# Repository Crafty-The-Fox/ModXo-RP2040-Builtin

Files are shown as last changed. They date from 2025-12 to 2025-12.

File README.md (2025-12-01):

# ModXo-RP2040-Included-Edition

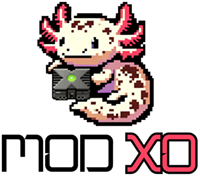
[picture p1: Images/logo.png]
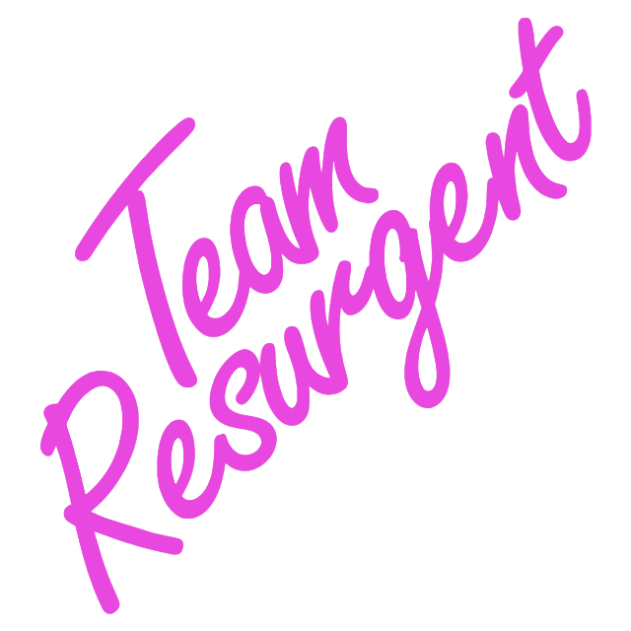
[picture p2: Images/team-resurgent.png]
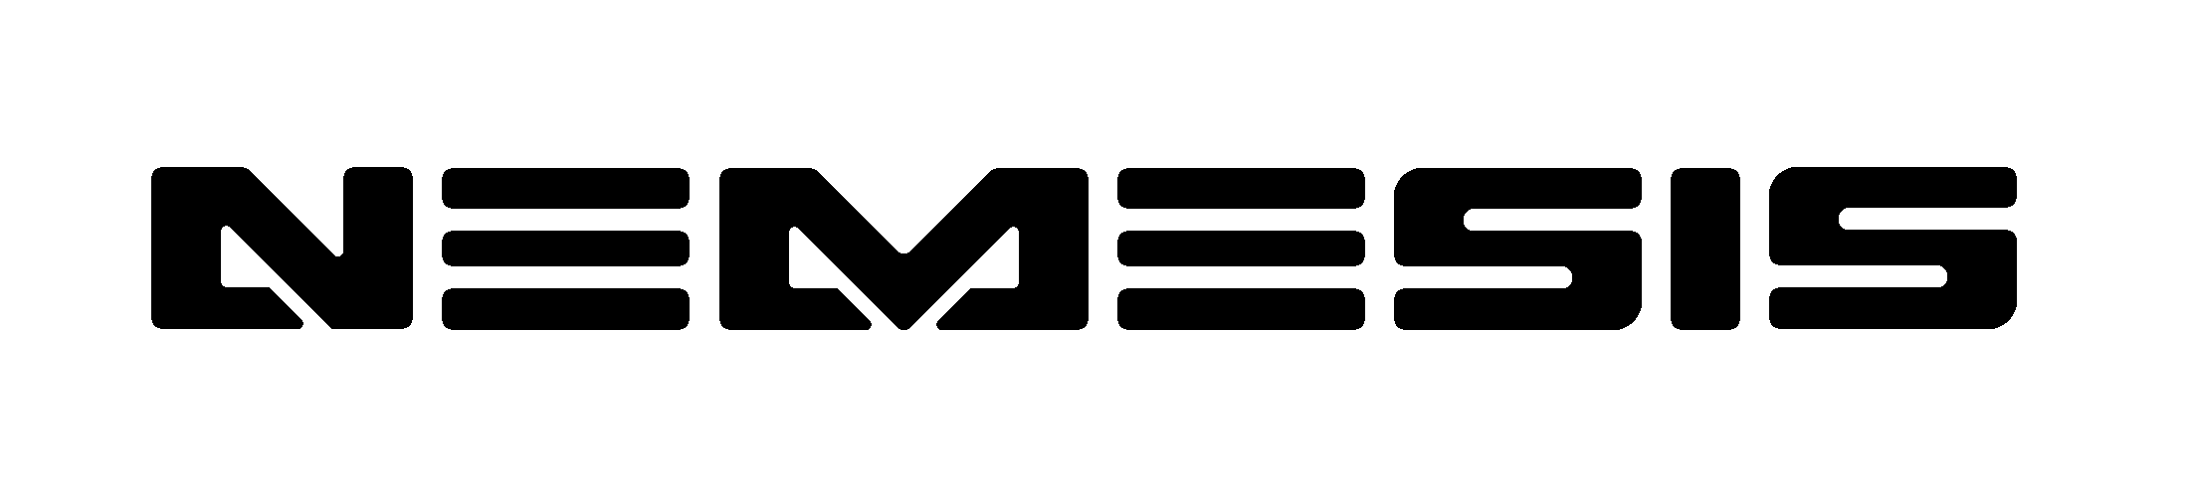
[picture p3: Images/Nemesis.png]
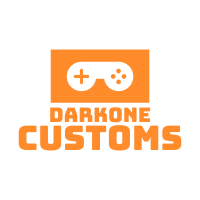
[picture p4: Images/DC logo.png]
   



A carrier board for the ModXo V1.0 with added support for Epimetheus. Based off of Darkone83's work. (reversed from gerbers and provided documents on the github page)

NOTE: anything after this is from the other repo.

This is designed around Team Resutgent's and Shalx's work on ModXo an open-source modchip, with additional support for OfficialTeamUIX's Epimetheus incorporated into the PCB

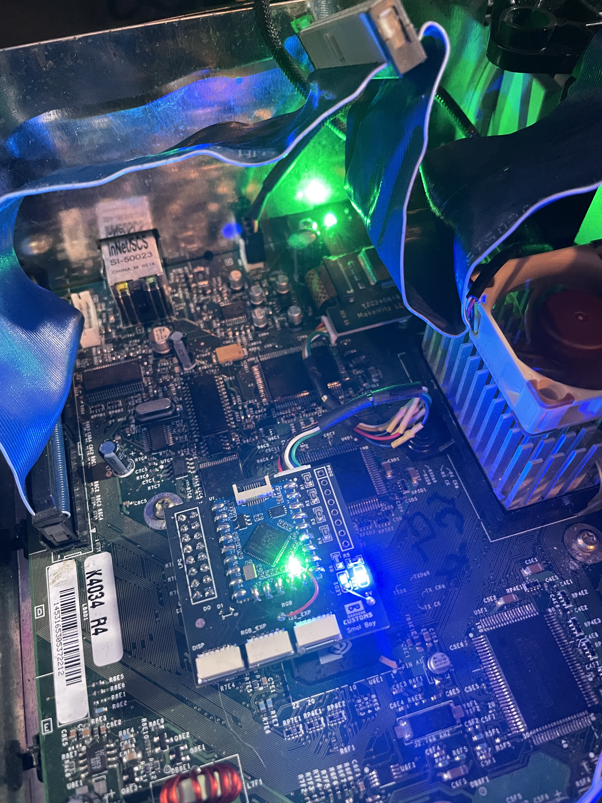
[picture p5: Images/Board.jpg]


Mouser Cart: <a href="https://www.mouser.com/ProjectManager/ProjectDetail.aspx?AccessID=a62729557a">Here</a>

RP2040 Tiny: <a href="https://www.aliexpress.us/item/3256805837992528.html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">AliExpress</a>, <a href="https://www.amazon.com/gp/product/B0CHDW1MY5/ref=ppx_yo_dt_b_asin_title_o02_s00?ie=UTF8&psc=1">Amazon</a>

JST SH 6 Pin Cables: 

<a href="https://www.aliexpress.us/item/3256804332710255.html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,scm-url:1007.40050.354490.0,pvid:6b58b5af-718a-4929-bfb1-9a0c24fd9d3c,tpp_buckets:668%232846%238112%231997&pdp_npi=4%40dis%21USD%210.46%210.40%21%21%210.46%210.40%21%402103241117302619299196939e5dfc%2112000029449896682%21rec%21US%21196794698%21X&utparam-url=scene%3ApcDetailTopMoreOtherSeller%7Cquery_from%3A">AliExpress</a> Select 100mm length, 6 Pin 10 Pcs, SH 1.0MM Dual for Color, Request same direction!!!

Or if you want to build out your own you can use this listing on <a href="https://www.amazon.com/gp/product/B0BKSNMCV4/ref=ppx_yo_dt_b_asin_title_o03_s00?ie=UTF8&psc=1">Amazon</a>

For more information on the software side of things and the ModXo project please visit: https://github.com/Team-Resurgent/Modxo

For more information on Epimetheus please visit: https://github.com/OfficialTeamUIX/Epimetheus 

### Notice

No firmware is provided for the STM32 you will need to either code your own firmware or legally obtain a firmware image

#### Builder's note

If your XBOX is a revision 1.6 you will need to rebuild the LPC manually or use a LPC rebuild PCB.

# Purchase

Fully assembled boards and PCB's can be purchased via <a href="https://darkonecustoms.com">Darkone Customs</a>

PCB Only: <a href="https://www.darkonecustoms.com/store/p/modxo-epimetheus-pcb">Here</a>

Fully Assembled Board: <a href="https://www.darkonecustoms.com/store/p/modxo-epimetheus-fully-assembled">Here</a> *Fully assembled boards do not contain any firmware for the STM32*

# Navigation

Both the Bom and iBOMS are located in the root folder. iBOMS are included for the full-size board and the new Smol revision, Large board has been moved to archive

Archive: Will contain older functional gerbers and pick and place files as the board revs, along with older board images and older iBOMS.

Images: Contains branding images along with PCB images for the full-size and the Smol board, the schematic is also included here and is the same for both boards along with images of the various header pinouts and soldering locations

Smol: Contains gerbers for the Smol board along with the pick-and-place file

# Assembly

### ModXo

It's recommended to assemble the ModXo potion of the board first and test it. These parts include U1, D1, LED2, R1-4, R6, and the LPC headder. After functionality has been confirmed move on to the VCC circuit assembly

### VCC circuit

The VCC Circuit pulls 5V and GND from the LPC 5V on the 5V pad and GND can be found on PINs 2,12. The VCC circuit consists of the following parts U5, L1, C1-C2. After assembly, you can test PIN 5 of U5 to ensure a stable 3.3V output. Once you have confirmed you have 3.3V continue to assemble the STM32 circuit

### STM32

The STM32F030C8C6 is the core of the Epimetheus functionality portion of the board these components include U2. R7-10, C3-C6. Do not install R9 until you have programmed your STM32. Once assembly is complete you can proceed to program your STM32 Review the NRST Harness diagram and temporarily install it for programming. The NRST wire will connect to the top pad of R9 (the one closest to the MCU) and the GND side to any viable GND source. Remove the NRST harness once you have verified and tested your firmware. Install R9 to complete the STM32 circuit. SDA is pulled directly from PIN 13 of the LPC header and SCL is pulled directly from PIN 14. Pinouts will be listed below. Proceed to Port assembly

#### STM32 PWR and Enable
Attach a +5V source to the 5V pad on the topside of the board. On the back of the board jumper, both boxes are labeled enable with a solder blob. This was designed this way to assist in isolating the STM32 and the ModXo. As a quick tap, you can pull +5V from the bottom of LED2. 

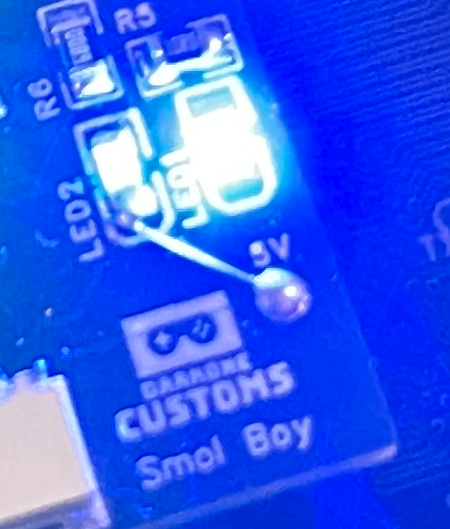
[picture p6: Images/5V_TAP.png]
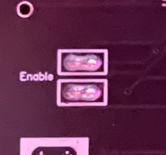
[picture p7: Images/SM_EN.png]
 

### Port Assembly

Install U3, DISP, i2c_EXP, RGB_EXP, if using the RGB_EXP port install the jumper wire from the tiny to the RGB TP to enable the functionality.

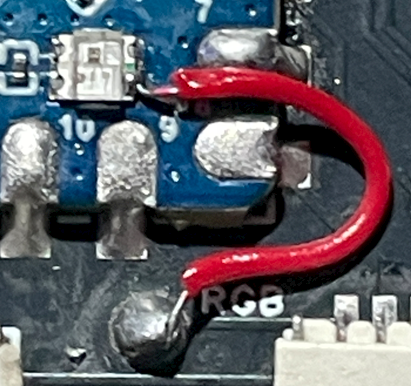
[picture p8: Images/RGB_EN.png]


### Notice

Soldering in the header for PROG is optional as you can insert pins and lightly wedge them in place to program the chip, R5, R6, LED1, and LED2 are optional. LED2 needs to be installed reverse of what the silk screen has labeled

# Installation

## 1.0 - 1.4

Install your pin header, Run a short wire from any suitable D0 point to either ground or the D0 point on the ModXo-Basic. Plug-in your ModXo-Basic to the XBOX LPC port (after you have flashed your favorite firmware) and enjoy.

#### D0 Point options

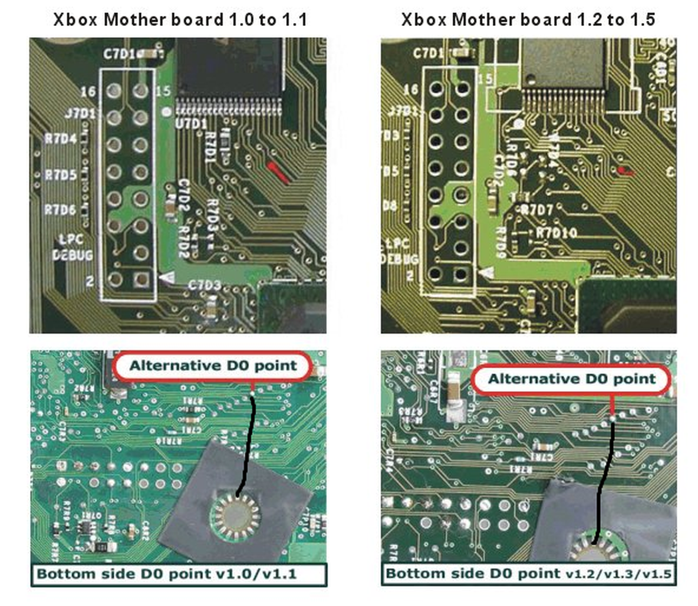
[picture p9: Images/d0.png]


## 1.6

Either install a LPC rebuild QSB or rebuild your LPC per the rebuild diagram below. Plug-in your ModXo-Basic to the XBOX LPC port (after you have flashed your favorite firmware) and enjoy.

#### 1.6 LPC rebuild

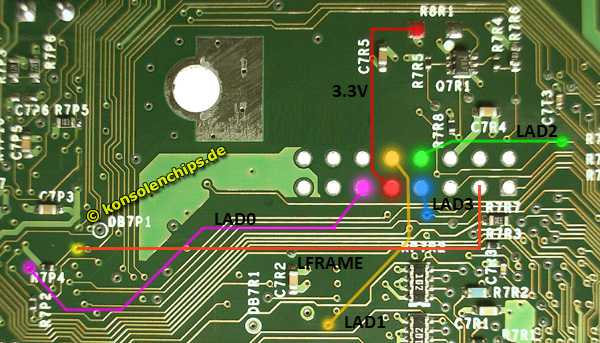
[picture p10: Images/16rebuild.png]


# Pinouts 

Xbox LPC

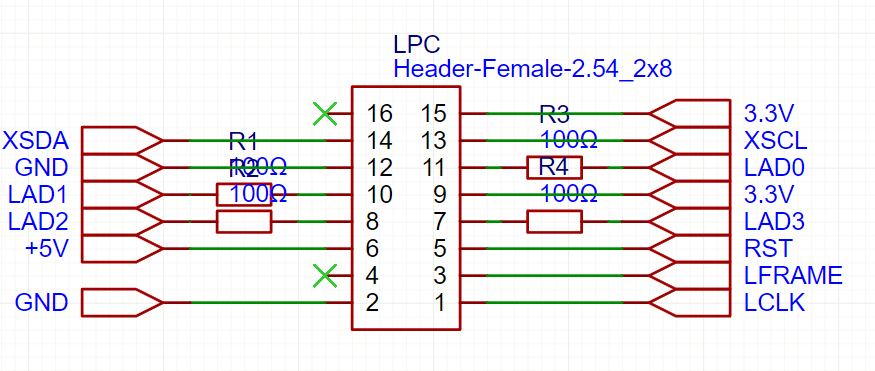
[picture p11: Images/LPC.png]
atl_text


Prog: 

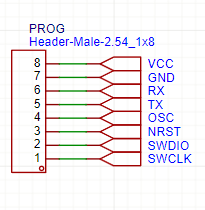
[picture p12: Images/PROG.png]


U3: 

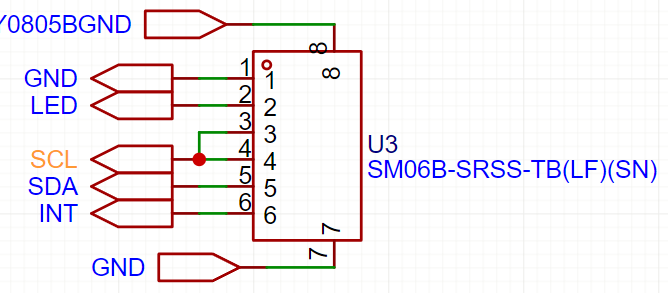
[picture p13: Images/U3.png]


RGB_EXP: 

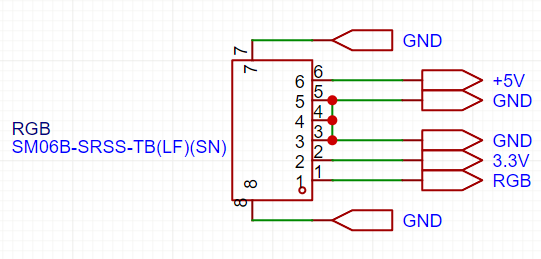
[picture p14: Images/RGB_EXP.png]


i2c_EXP: 

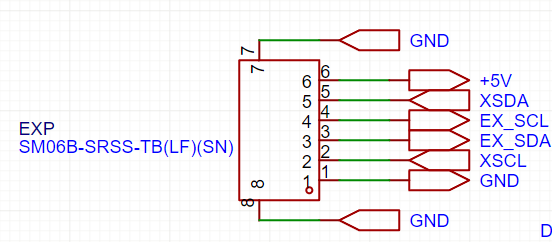
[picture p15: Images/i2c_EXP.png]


DISP: 

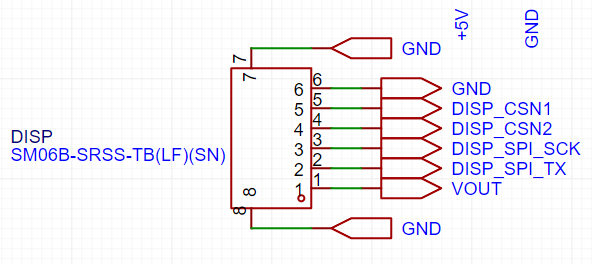
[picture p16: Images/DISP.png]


NRST Harnes:

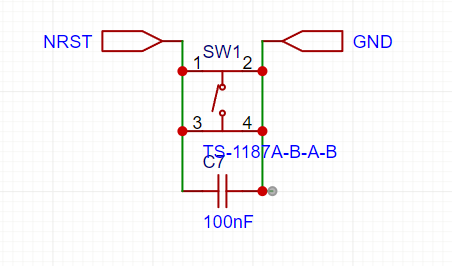
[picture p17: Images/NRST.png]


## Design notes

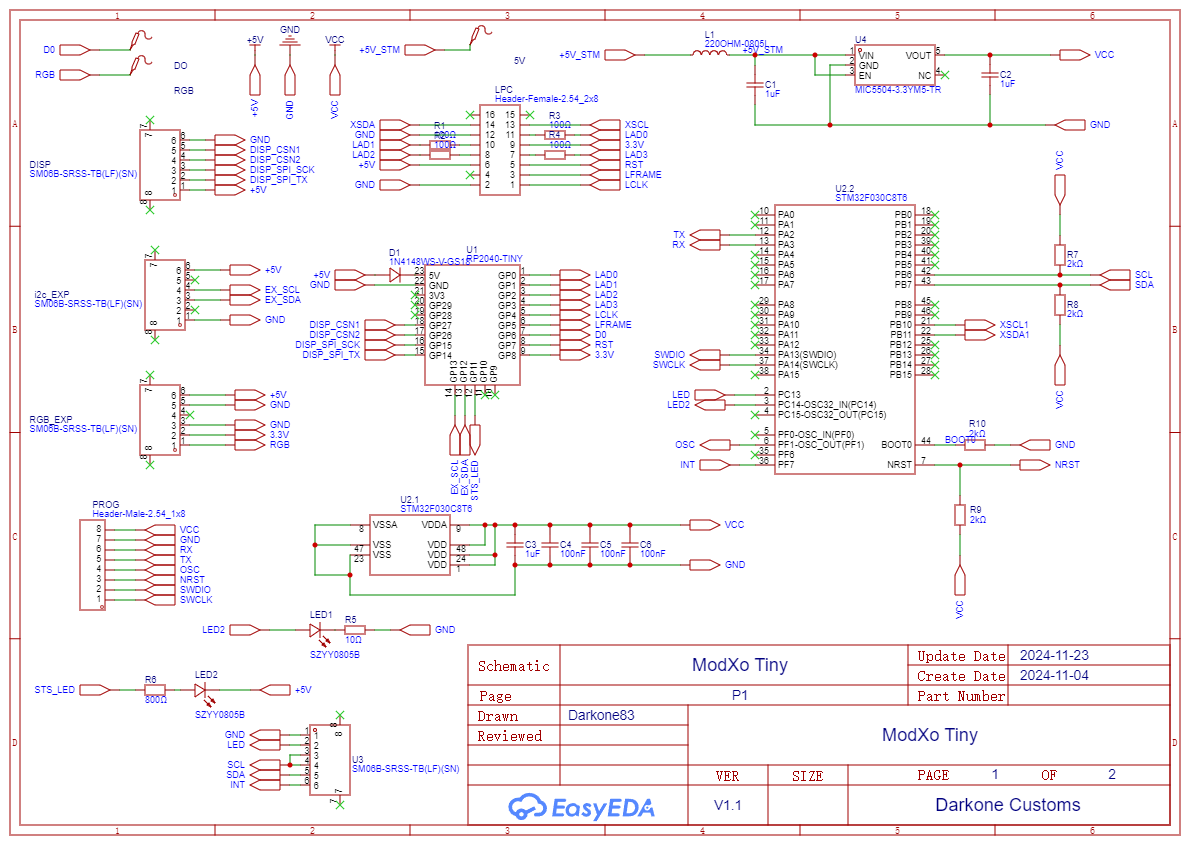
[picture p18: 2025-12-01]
Images/Schematic_ModXo+Epimetheus.png

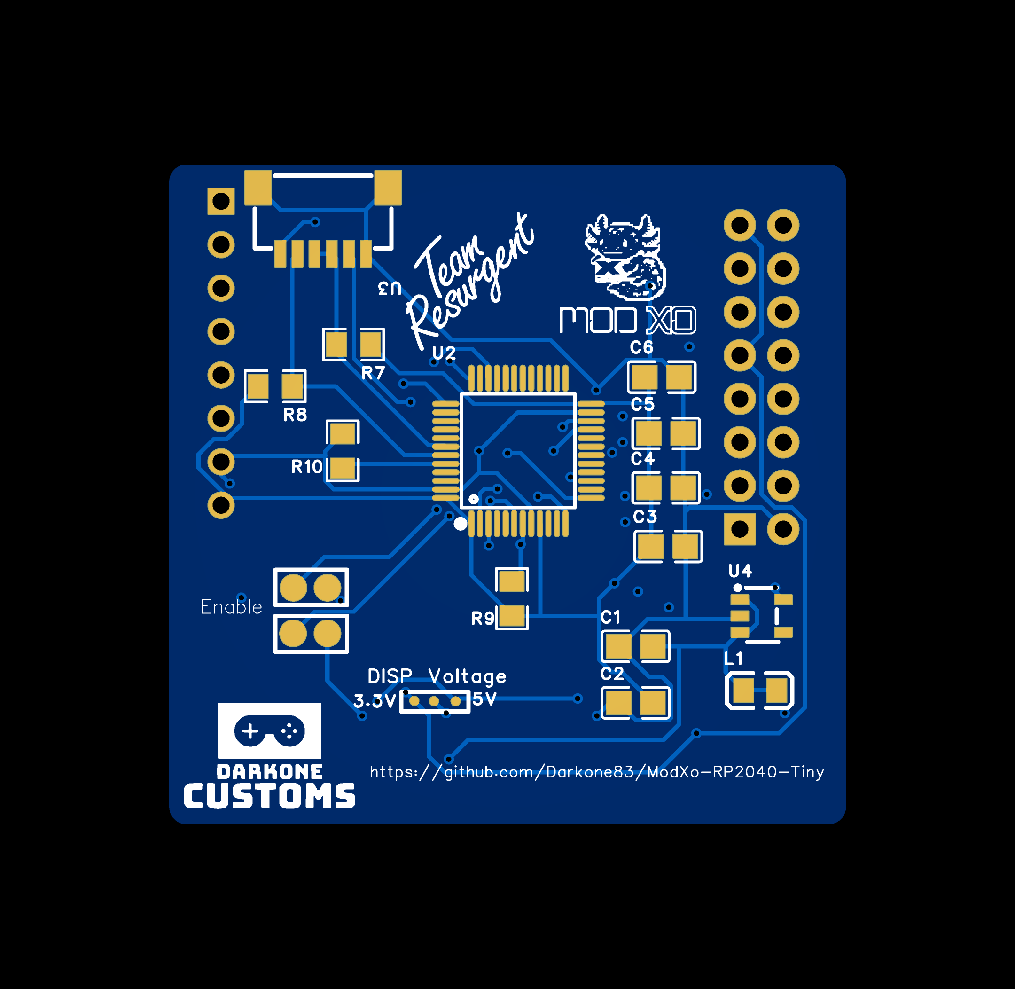
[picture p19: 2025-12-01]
Images/PCB Smol Back.png

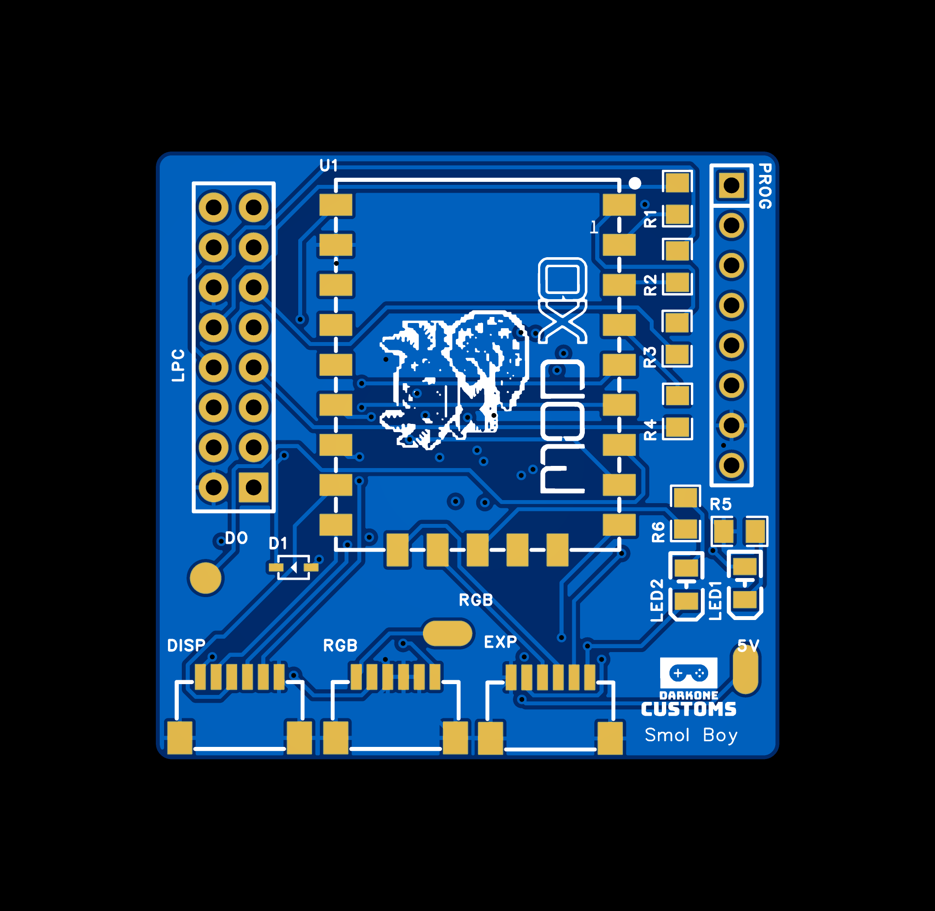
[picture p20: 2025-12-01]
Images/PCB Smol Front.png

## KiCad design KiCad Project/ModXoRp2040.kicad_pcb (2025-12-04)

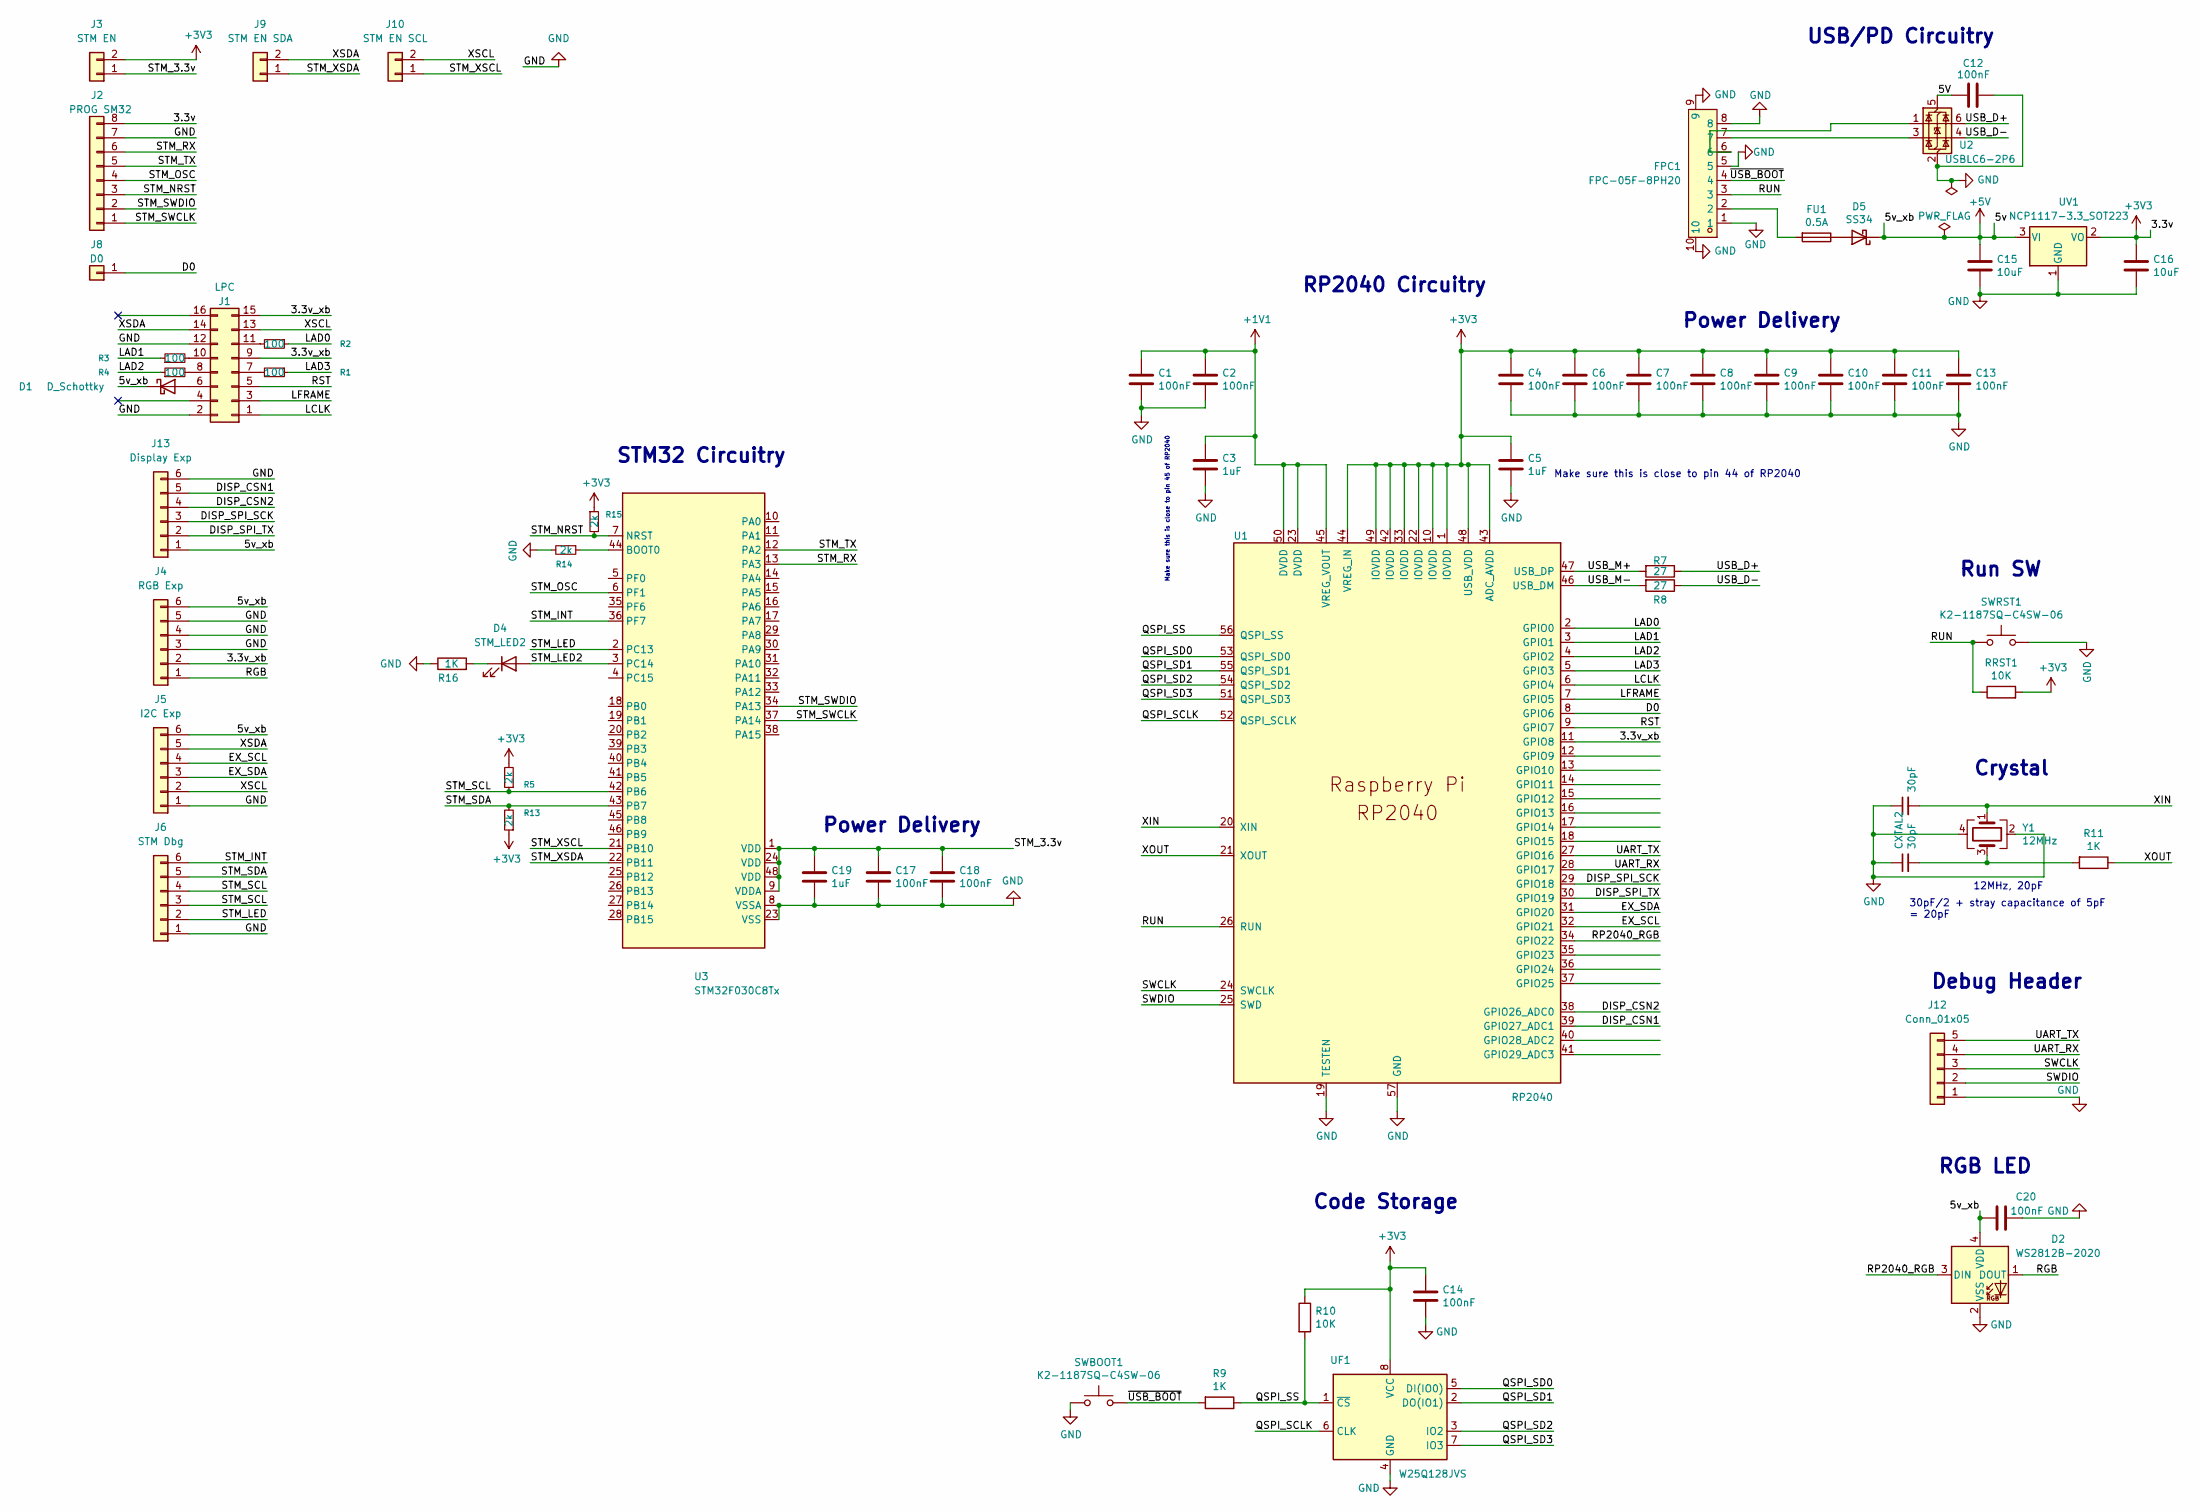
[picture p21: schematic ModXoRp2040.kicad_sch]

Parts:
C1, C2, C4, C6, C7, C8, C9, C10, C11, C12, C13, C14, C17, C18, C20: 100nF; C_0201_0603Metric; LCSC C1525
C3, C5, C19: 1uF; C_0201_0603Metric; LCSC C52923
C15, C16: 10uF; C_0201_0603Metric; LCSC C15850
CXTAL1, CXTAL2: 30pF; C_0201_0603Metric; LCSC C1570
D1: D_Schottky; D_SMA
D2: WS2812B-2020; LED_WS2812B-2020_PLCC4_2.0x2.0mm
D4: STM_LED2; LED_0402_1005Metric_Pad0.77x0.64mm_HandSolder; LCSC C165977
D5: SS34; D_SMA; LCSC C8678
FPC1: FPC-05F-8PH20; FPC-SMD_8P-P0.50_FPC-05F-8PH20; LCSC Part C2856797
FU1: 0.5A; Fuse_1206_3216Metric_Pad1.42x1.75mm_HandSolder; LCSC C70068
J1: LPC; PinSocket_2x08_P2.54mm_Vertical
J2: PROG SM32; PinSocket_1x08_P2.54mm_Vertical
J3: STM EN; SolderJumper-2_P1.3mm_Open_RoundedPad1.0x1.5mm
J4: RGB Exp; JST_SH_SM06B-SRSS-TB_1x06-1MP_P1.00mm_Horizontal
J5: I2C Exp; JST_SH_SM06B-SRSS-TB_1x06-1MP_P1.00mm_Horizontal
J6: STM Dbg; JST_SH_SM06B-SRSS-TB_1x06-1MP_P1.00mm_Horizontal
J8: D0; TestPoint_Pad_D1.5mm
J9: STM EN SDA; SolderJumper-2_P1.3mm_Open_RoundedPad1.0x1.5mm
J10: STM EN SCL; SolderJumper-2_P1.3mm_Open_RoundedPad1.0x1.5mm
J12: Conn_01x05; PinSocket_1x05_P2.00mm_Vertical
J13: Display Exp; JST_SH_SM06B-SRSS-TB_1x06-1MP_P1.00mm_Horizontal
R1, R2, R3, R4: 100; R_0201_0603Metric
R5, R13, R14, R15: 2k; R_0201_0603Metric
R7, R8: 27; R_0201_0603Metric; LCSC C25190
R9: 1K; R_0201_0603Metric; LCSC C21190
R10: 10K; R_0402_1005Metric; LCSC C25804
R11: 1K; R_0201_0603Metric; LCSC C11702
R16: 1K; R_0402_1005Metric; LCSC C21190
RRST1: 10K; R_0402_1005Metric; LCSC C25804
SWBOOT1: K2-1187SQ-C4SW-06; SolderJumper-2_P1.3mm_Open_RoundedPad1.0x1.5mm
SWRST1: K2-1187SQ-C4SW-06; SolderJumper-2_P1.3mm_Open_RoundedPad1.0x1.5mm
U1: RP2040; QFN-56-1EP_7x7mm_P0.4mm_EP3.2x3.2mm; LCSC C2040
U2: USBLC6-2P6; SOT-666
U3: STM32F030C8Tx; LQFP-48_7x7mm_P0.5mm
UF1: W25Q128JVS; SOIC-8_5.275x5.275mm_P1.27mm; LCSC C97521
UV1: NCP1117-3.3_SOT223; SOT-223-3_TabPin2; LCSC C146799
Y1: 12MHz; Crystal_SMD_3225-4Pin_3.2x2.5mm; LCSC C9002

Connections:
+1V1: C1.1, C2.1, C3.1, U1.23 (DVDD), U1.45 (VREG_VOUT), U1.50 (DVDD)
+3V3: C4.1, C5.1, C6.1, C7.1, C8.1, C9.1, C10.1, C11.1, C13.1, C14.1, C16.1, J2.8, J3.2, R5.2, R10.1, R13.1, R15.1, RRST1.2, U1.1 (IOVDD), U1.10 (IOVDD), U1.22 (IOVDD), U1.33 (IOVDD), U1.42 (IOVDD), U1.43 (ADC_AVDD), U1.44 (VREG_IN), U1.48 (USB_VDD), U1.49 (IOVDD), UF1.8 (VCC), UV1.2 (VO)
+5V: C15.1, C20.1, D1.1 (K), D2.4 (VDD), D5.1 (K), J4.6, J5.6, J13.1, UV1.3 (VI)
/3.3v_xb: J1.9, J1.15, J4.2, U1.11 (GPIO8)
/5V: C12.2, U2.5 (VBUS)
/D0: J8.1, U1.8 (GPIO6)
/DISP_CSN1: J13.5, U1.39 (GPIO27_ADC1)
/DISP_CSN2: J13.4, U1.38 (GPIO26_ADC0)
/DISP_SPI_SCK: J13.3, U1.29 (GPIO18)
/DISP_SPI_TX: J13.2, U1.30 (GPIO19)
/EX_SCL: J5.4, U1.32 (GPIO21)
/EX_SDA: J5.3, U1.31 (GPIO20)
/LAD0: R2.1, U1.2 (GPIO0)
/LAD1: R3.1, U1.3 (GPIO1)
/LAD2: R4.1, U1.4 (GPIO2)
/LAD3: R1.1, U1.5 (GPIO3)
/LCLK: J1.1, U1.6 (GPIO4)
/LFRAME: J1.3, U1.7 (GPIO5)
/QSPI_SCLK: U1.52 (QSPI_SCLK), UF1.6 (CLK)
/QSPI_SD0: U1.53 (QSPI_SD0), UF1.5 (DI(IO0))
/QSPI_SD1: U1.55 (QSPI_SD1), UF1.2 (DO(IO1))
/QSPI_SD2: U1.54 (QSPI_SD2), UF1.3 (IO2)
/QSPI_SD3: U1.51 (QSPI_SD3), UF1.7 (IO3)
/QSPI_SS: R9.1, R10.2, U1.56 (QSPI_SS), UF1.1 (~CS)
/RGB: D2.1 (DOUT), J4.1
/RP2040_RGB: D2.3 (DIN), U1.34 (GPIO22)
/RST: J1.5, U1.9 (GPIO7)
/RUN: FPC1.3, RRST1.1, SWRST1.1, U1.26 (RUN)
/STM_3.3v: C17.1, C18.1, C19.1, J3.1, U3.1 (VDD), U3.9 (VDDA), U3.24 (VDD), U3.48 (VDD)
/STM_INT: J6.6, U3.36 (PF7)
/STM_LED: J6.2, U3.2 (PC13)
/STM_LED2: D4.2 (A), U3.3 (PC14)
/STM_NRST: J2.3, R15.2, U3.7 (NRST)
/STM_OSC: J2.4, U3.6 (PF1)
/STM_RX: J2.6, U3.13 (PA3)
/STM_SCL: J6.3, J6.4, R5.1, U3.42 (PB6)
/STM_SDA: J6.5, R13.2, U3.43 (PB7)
/STM_SWCLK: J2.1, U3.37 (PA14)
/STM_SWDIO: J2.2, U3.34 (PA13)
/STM_TX: J2.5, U3.12 (PA2)
/STM_XSCL: J10.1, U3.21 (PB10)
/STM_XSDA: J9.1, U3.22 (PB11)
/SWCLK: J12.3, U1.24 (SWCLK)
/SWDIO: J12.2, U1.25 (SWD)
/UART_RX: J12.4, U1.28 (GPIO17)
/UART_TX: J12.5, U1.27 (GPIO16)
/USB_D+: R7.1, U2.6 (I/O1)
/USB_D-: R8.1, U2.4 (I/O2)
/USB_M+: R7.2, U1.47 (USB_DP)
/USB_M-: R8.2, U1.46 (USB_DM)
/XIN: CXTAL1.2, U1.20 (XIN), Y1.1
/XOUT: R11.1, U1.21 (XOUT)
/XSCL: J1.13, J5.2, J10.2
/XSDA: J1.14, J5.5, J9.2
/~USB_BOOT: FPC1.4, R9.2, SWBOOT1.2
GND: C1.2, C2.2, C3.2, C4.2, C5.2, C6.2, C7.2, C8.2, C9.2, C10.2, C11.2, C12.1, C13.2, C14.2, C15.2, C16.2, C17.2, C18.2, C19.2, C20.2, CXTAL1.1, CXTAL2.1, D2.2 (VSS), FPC1.1, FPC1.5, FPC1.8, FPC1.9, FPC1.10, J1.2, J1.12, J2.7, J4.3, J4.4, J4.5, J5.1, J6.1, J12.1, J13.6, R14.2, R16.1, SWBOOT1.1, SWRST1.2, U1.19 (TESTEN), U1.57 (GND), U2.2 (GND), U3.8 (VSSA), U3.23 (VSS), UF1.4 (GND), UV1.1 (GND), Y1.2, Y1.4
unnamed: CXTAL2.2, R11.2, Y1.3
unnamed: D1.2 (A), J1.6
unnamed: D4.1 (K), R16.2
unnamed: D5.2 (A), FU1.1
unnamed: FPC1.2, FU1.2
unnamed: FPC1.6, U2.1 (I/O1)
unnamed: FPC1.7, U2.3 (I/O2)
unnamed: J1.7, R1.2
unnamed: J1.8, R4.2
unnamed: J1.10, R3.2
unnamed: J1.11, R2.2
unnamed: R14.1, U3.44 (BOOT0)

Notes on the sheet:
Power Delivery
RP2040 Circuitry
Make sure this is close to pin 45 of RP2040
Make sure this is close to pin 44 of RP2040
12MHz, 20pF
Run SW
STM32 Circuitry
30pF/2 + stray capacitance of 5pF = 20pF
USB/PD Circuitry
RGB LED
Code Storage
Debug Header
Crystal

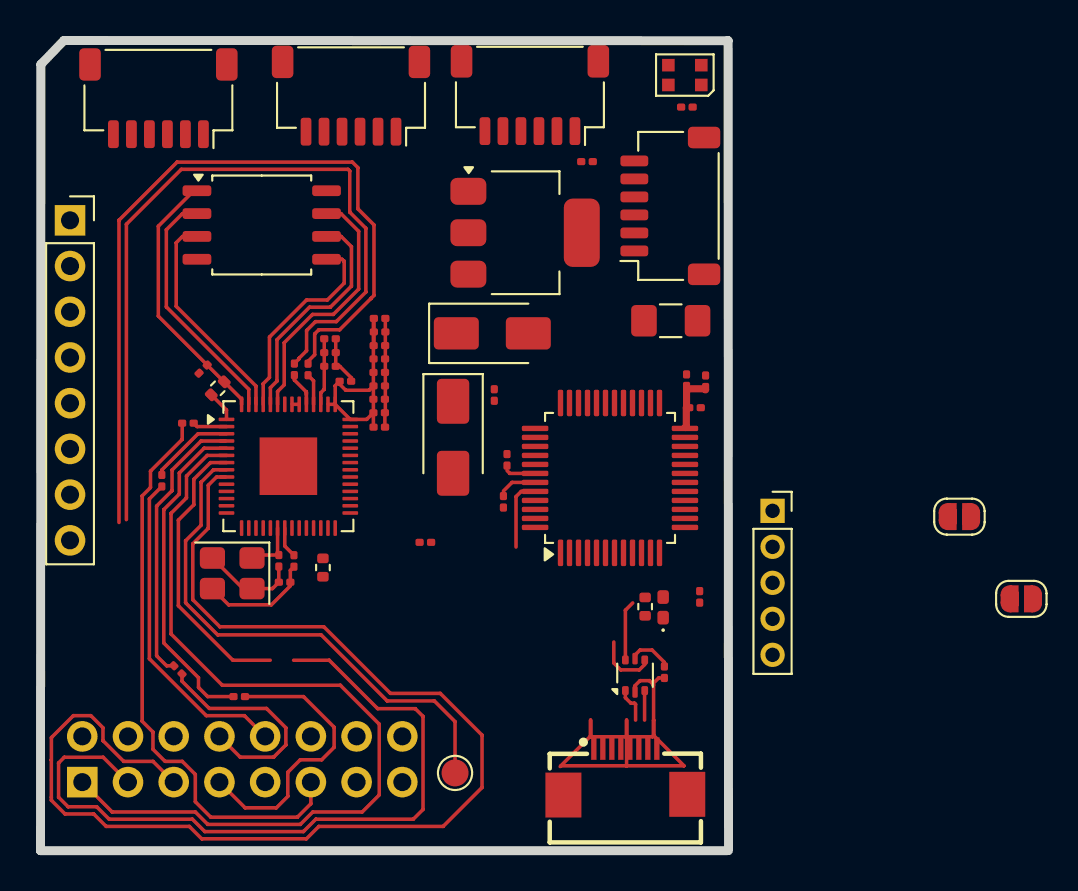
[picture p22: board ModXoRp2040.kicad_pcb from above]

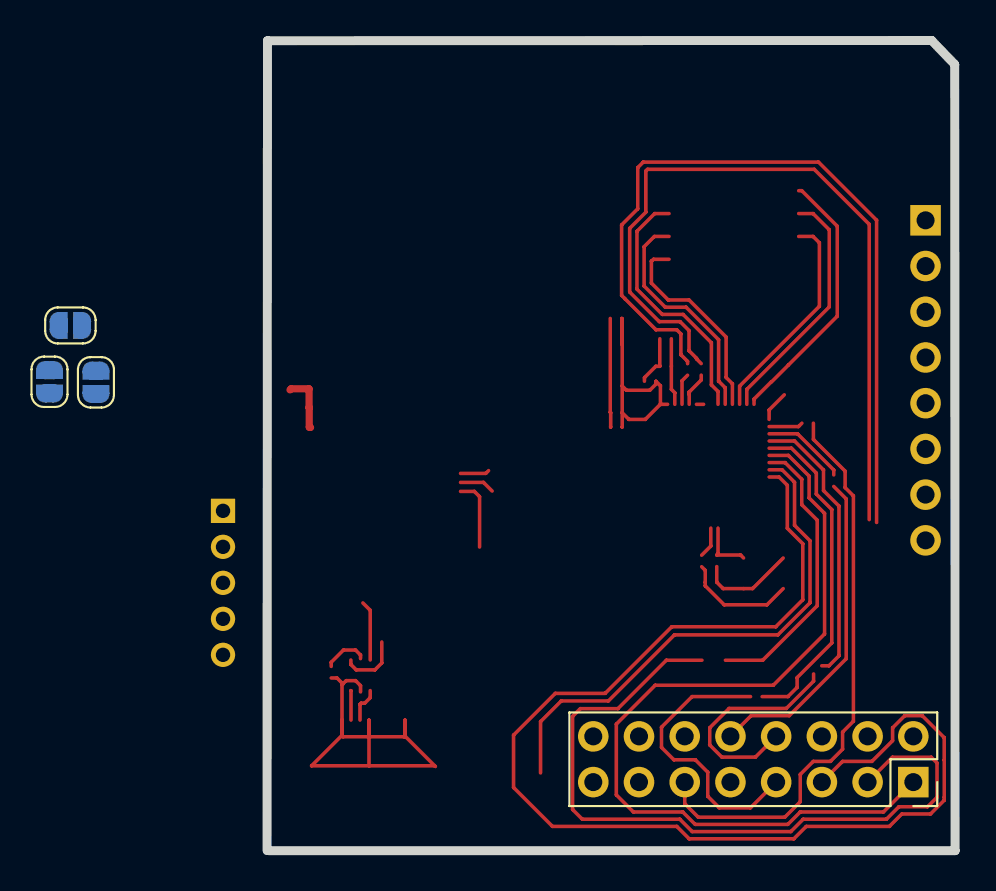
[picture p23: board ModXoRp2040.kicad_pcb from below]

Board: 2 copper layers, 38.2 x 45.0 mm, 62 parts (4 on the bottom side), 68 nets.

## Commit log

2025-12-01 crap i messed some stuff up when moving it
    [RP2040 modchiprev3basiceditionrev10_1mmconnectors.GBL, RP2040 modchiprev3basiceditionrev10_1mmconnectors.GBO, RP2040 modchiprev3basiceditionrev10_1mmconnectors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]
2025-12-01 oops i had a bunch of stuff messed up, whatever
    [Drill_PTH_Through.DRL, Drill_PTH_Through_Via.DRL, Gerber_BoardOutlineLayer.GKO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]
2025-12-01 start pcb layout
    [ModXoRp2040.kicad_pcb, ModXoRp2040.kicad_sch]
2025-12-02 finish schematics, start on pcb layout
    [ModXoRp2040.kicad_pcb, ModXoRp2040.kicad_sch]
2025-12-03 continue layout, put some tracks down
    need to rotate rp2040 otherwise layout is pretty much final?
    [ModXoRp2040.kicad_pcb, ModXoRp2040.kicad_sch]
2025-12-04 semi update
    [ModXoRp2040.kicad_pcb, ModXoRp2040.kicad_sch]
